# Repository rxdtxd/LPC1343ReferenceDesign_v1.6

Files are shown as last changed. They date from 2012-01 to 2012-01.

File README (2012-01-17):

This is a version of microBuilder.eu LPC1343 Reference Board [1],
slightly modified:

- the ocillator footprint is replaced with a HC49/S, these crystals
  are available locally and cheaper;
- spacings are slightly increased (manufacturer requirements);
- silkscreen is now retarded.

[1]: http://www.microbuilder.eu/Projects/LPC1343ReferenceDesign.aspx

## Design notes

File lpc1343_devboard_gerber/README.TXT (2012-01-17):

Bottom Copper     (GBL)
Bottom Silkscreen (GBO)
Bottom Soldermask (GBS)
Top Copper        (GTL)
Top Silkscreen    (GTO)
Top Soldermask 	  (GTS)
Top Paste      	  (GTP)
Drill File 	  (TXT)

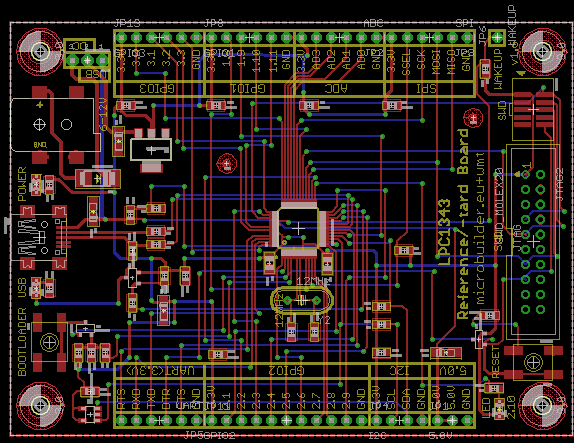
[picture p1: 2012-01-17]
Board.png

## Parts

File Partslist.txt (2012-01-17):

Partlist

Exported from LPC1343_BaseBoard_V1.6.brd at 1/17/12 9:31 PM

EAGLE Version 6.0.0 Copyright (c) 1988-2011 CadSoft

Assembly variant: 

Part     Value          Package         Library      Position (inch)       Orientation

BTN1     RESET          EVQ-Q2          microbuilder (3.48015748 0.48625984) R180
BTN2     ISP            EVQ-Q2          microbuilder (0.26015748 0.62)     R270
C1       16pF           0603            microbuilder (1.87094488 0.68984252) R90
C2       10µF           EIA3216-18/A-R  microbuilder (0.72015748 1.9615748) R90
C3       10µF           EIA3216-18/A-R  microbuilder (1.02015748 0.8315748) R90
C4       10µF           EIA3216-18/A-R  microbuilder (0.55015748 1.4915748) R270
C5       0.1µF          0603            microbuilder (3.19015748 0.80062992) R180
C6       0.1µF          0603            microbuilder (1.99015748 2.2015748) R0
C7       10µF           0805            microbuilder (2.11015748 1.1415748) R270
C8       10µF           0805            microbuilder (1.72389764 1.1484252) R270
C9       0.1µF          0603            microbuilder (2.54015748 2.2015748) R0
C10      0.1µF          0603            microbuilder (2.47015748 0.55)     R0
C11      0.1µF          0603            microbuilder (0.54047244 0.55094488) R270
C12      0.1µF          0603            microbuilder (1.16267717 1.06440945) R270
C13      10µF           EIA3216-18/A-R  microbuilder (2.90015748 0.55)     R180
C14      16pF           0603            microbuilder (2.02515748 0.69094488) R90
C15      0.1µF          0603            microbuilder (1.37015748 2.2015748) R0
C16      0.1µF          0603            microbuilder (1.38015748 0.54)     R0
C17      0.1µF          0603            microbuilder (0.77015748 2.2015748) R0
C18      0.1µF          0603            microbuilder (0.53015748 0.29)     R0
CN1      USBMINIB       USB-MINIB       microbuilder (0.19015748 1.32125984) R270
CN2      DC_2.0MM       DCJACK_2MM_SMT  microbuilder (0.19515748 2.0715748) R0
D1       BAT54C         SOT23-R         microbuilder (0.50015748 0.71094488) R0
D2       CDBA120-G      SMADIODE        microbuilder (0.58015748 1.7115748) R180
JP1      5.0V           1X03_ROUND      microbuilder (2.94015748 0.1)      R0
JP2      ADC            1X06_ROUND      microbuilder (2.19015748 2.65)     R180
JP3      SPI            1X06_ROUND      microbuilder (2.79015748 2.65)     R180
JP4      I2C            1X04_ROUND      microbuilder (2.59015748 0.1)      R0
JP5      UART           1X06_ROUND      microbuilder (0.99015748 0.1)      R180
JP6      WAKEUP         1X01_ROUND      microbuilder (3.24015748 2.6515748) R90
JP7      FIDUCIAL1X2.5  FIDUCIAL-1X2.5  microbuilder (3.08 2.11629921)     R0
JP8      GPIO1          1X06_ROUND      microbuilder (1.59015748 2.65)     R0
JP9      FIDUCIAL1X2.5  FIDUCIAL-1X2.5  microbuilder (1.44 1.81259843)     R0
JP11     GPIO2          1X11_ROUND      microbuilder (1.84015748 0.1)      R0
JP12     POWERSOURCE    JUMPER3         microbuilder (0.51149606 2.50275591) R180
JP13     GPIO3          1X06_ROUND      microbuilder (0.99015748 2.65)     R0
JTAG1                   2X05_1.27MM_SMT microbuilder (3.48015748 2.1715748) R270
JTAG2    SWD_MOLEX20    JTAG-ARM        microbuilder (3.48015748 1.2915748) R270
LED1     POWER          CHIPLED_0805    microbuilder (0.17015748 1.67125984) R0
LED2     2mA            CHIPLED_0805    microbuilder (3.25515748 0.17562992) R0
LED3     USB            CHIPLED_0805    microbuilder (0.17015748 0.98125984) R0
Q1       MMBT2907A      SOT23-R         microbuilder (0.81015748 1.0515748) R90
R1       20K            0603            microbuilder (0.45047244 0.55094488) R270
R2       10K            0603            microbuilder (2.47015748 0.86125984) R180
R3       10K            0603            microbuilder (2.47015748 0.74062992) R180
R4       10K            0603            microbuilder (2.62015748 1.2315748) R0
R5       10K            0603            microbuilder (3.16015748 2.4415748) R270
R6       1K             0603            microbuilder (0.62937008 0.55094488) R270
R7       100K           0603            microbuilder (0.97015748 1.5115748) R180
R8       1.0K           0603            microbuilder (3.22141732 0.31594488) R180
R9       150            0603            microbuilder (0.26015748 1.67125984) R270
R10      33             0603            microbuilder (0.97015748 1.2715748) R0
R11      33             0603            microbuilder (0.97015748 1.3615748) R0
R12      2K             0603            microbuilder (0.81015748 0.8815748) R270
R13      150            0603            microbuilder (0.26015748 0.98125984) R90
R14      10K            0603            microbuilder (0.80015748 1.4715748) R90
R15      10K            0603            microbuilder (1.02708661 1.06440945) R270
R19      1.5K           0603            microbuilder (0.81015748 1.2315748) R90
U1       LPC1343FBD48   LQFP48          microbuilder (1.92015748 1.37795276) R90
U2       LM1117(3.3)    SOT223-R        microbuilder (0.94015748 1.9015748) R180
U3       MCP130T        SOT23-R         microbuilder (3.11952756 0.64062992) R90
U4       24AA32AFT-I/OT SOT23-5         microbuilder (0.53015748 0.14)     R90
Y2       12MHz          HC49/S          crystal      (1.94015748 0.90094488) R180

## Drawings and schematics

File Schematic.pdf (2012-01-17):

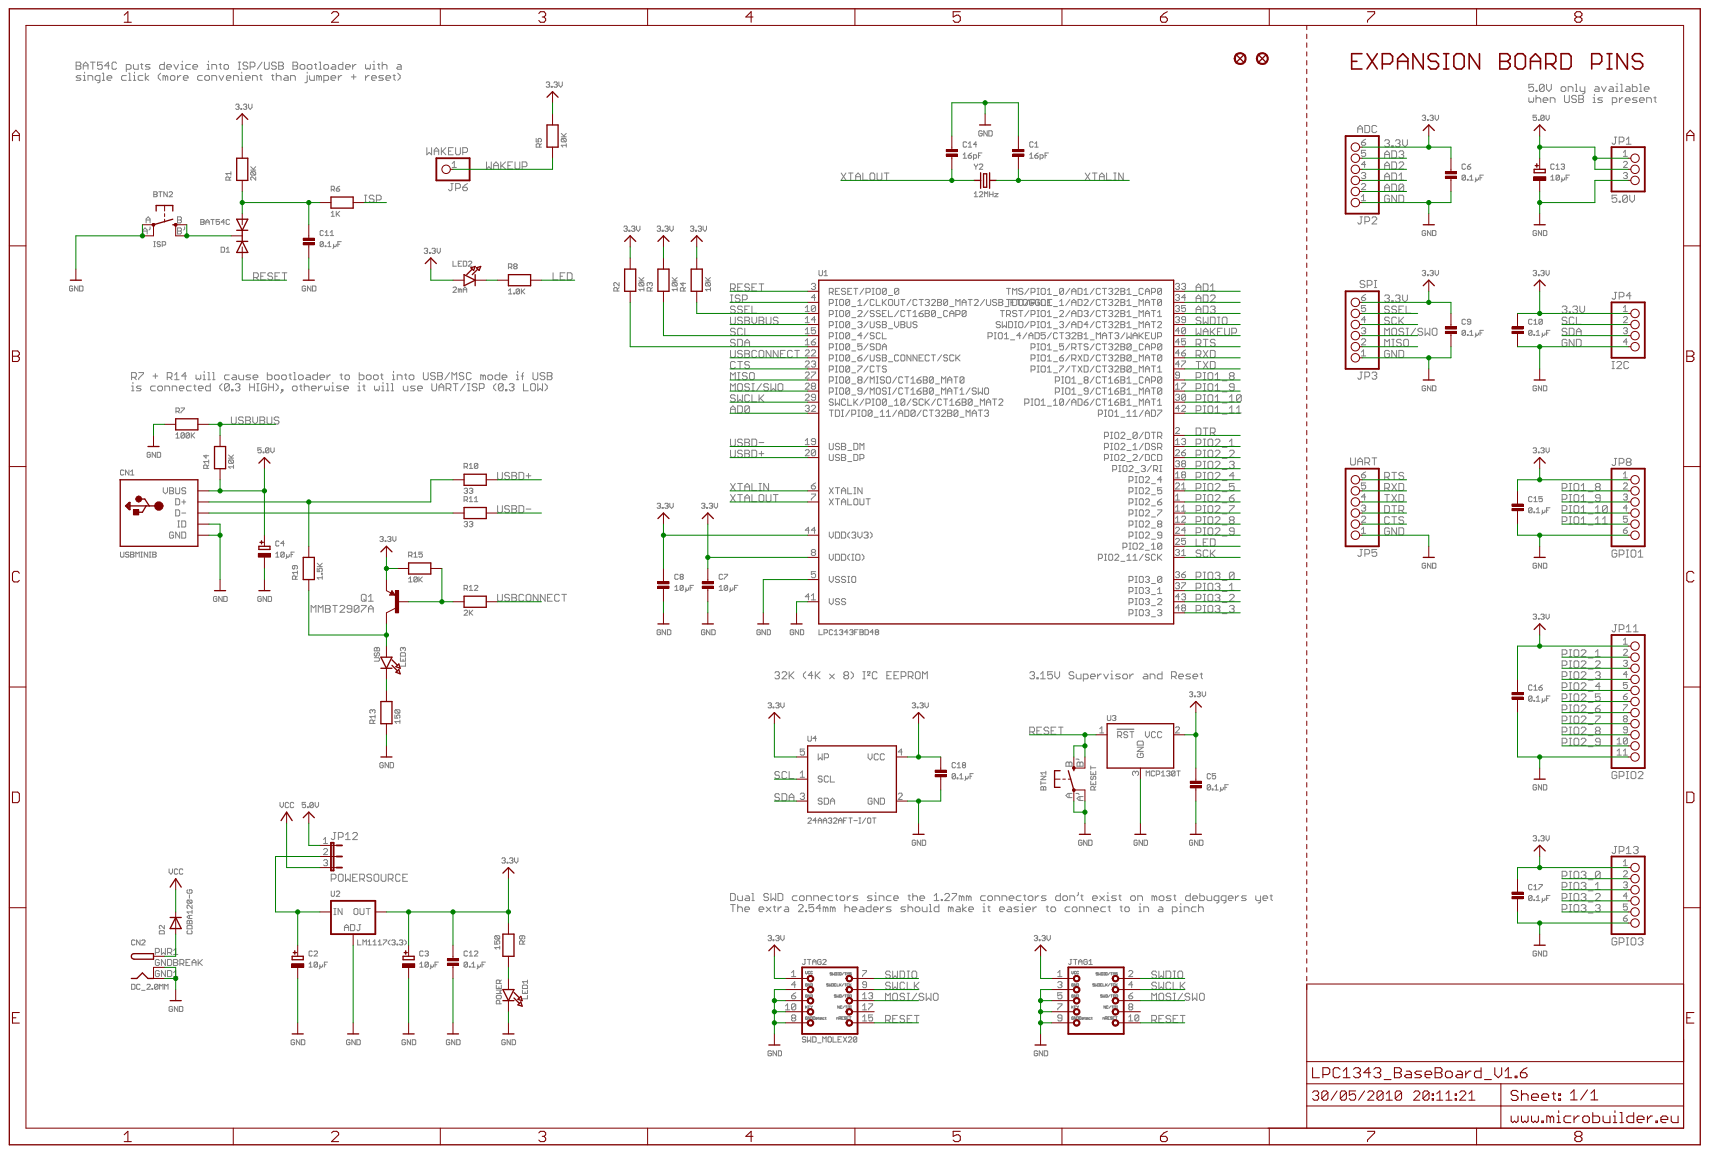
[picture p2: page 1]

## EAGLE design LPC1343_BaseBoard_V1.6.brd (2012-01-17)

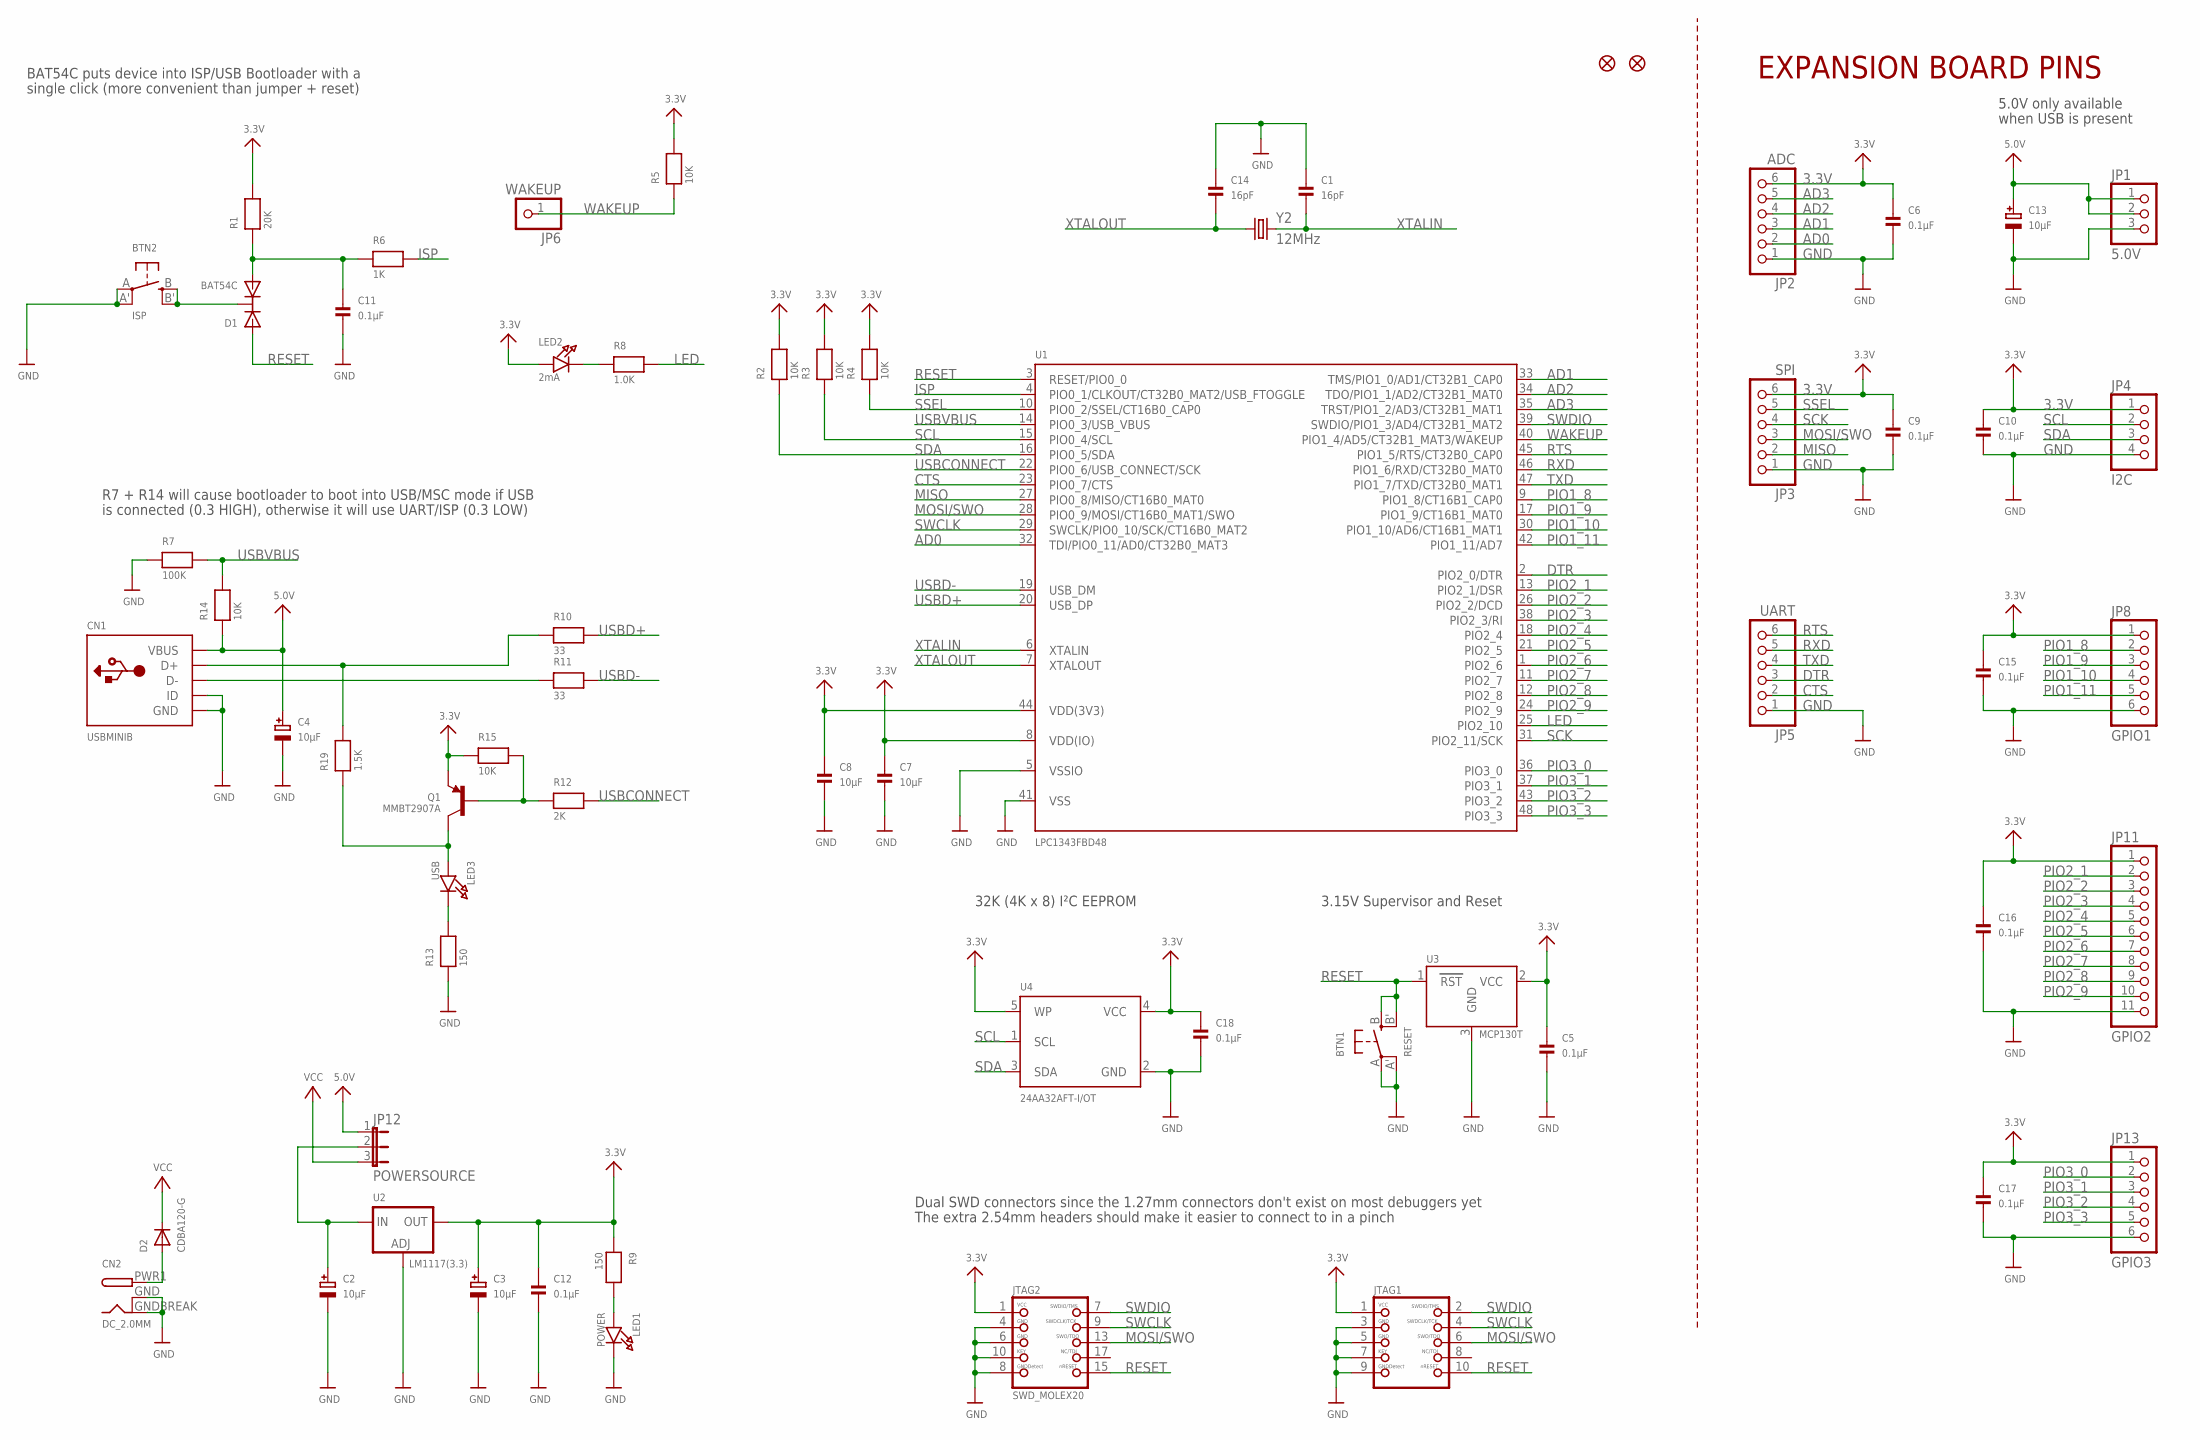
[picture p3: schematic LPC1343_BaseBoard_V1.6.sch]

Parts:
BTN1: RESET; EVQ-Q2
BTN2: ISP; EVQ-Q2
C1, C14: 16pF; 0603
C2, C3, C4, C13: 10µF; EIA3216-18/A-R
C5, C6, C9, C10, C11, C12, C15, C16, C17, C18: 0.1µF; 0603
C7, C8: 10µF; 0805
CN1: USBMINIB; USB-MINIB
CN2: DC_2.0MM; DCJACK_2MM_SMT
D1: BAT54C; SOT23-R
D2: CDBA120-G; SMADIODE
JP1: 5.0V; 1X03_ROUND
JP2: ADC; 1X06_ROUND
JP3: SPI; 1X06_ROUND
JP4: I2C; 1X04_ROUND
JP5: UART; 1X06_ROUND
JP6: WAKEUP; 1X01_ROUND
JP7, JP9: FIDUCIAL1X2.5; FIDUCIAL-1X2.5
JP8: GPIO1; 1X06_ROUND
JP11: GPIO2; 1X11_ROUND
JP12: POWERSOURCE; JUMPER3
JP13: GPIO3; 1X06_ROUND
JTAG1: JTAG-CORTEXM3; 2X05_1.27MM_SMT
JTAG2: SWD_MOLEX20; JTAG-ARM
LED1: POWER; CHIPLED_0805
LED2: 2mA; CHIPLED_0805
LED3: USB; CHIPLED_0805
Q1: MMBT2907A; SOT23-R
R1: 20K; 0603
R2, R3, R4, R5, R14, R15: 10K; 0603
R6: 1K; 0603
R7: 100K; 0603
R8: 1.0K; 0603
R9, R13: 150; 0603
R10, R11: 33; 0603
R12: 2K; 0603
R19: 1.5K; 0603
U1: LPC1343FBD48; LQFP48
U2: LM1117(3.3); SOT223-R
U3: MCP130T; SOT23-R
U4: 24AA32AFT-I/OT; SOT23-5
Y2: 12MHz; HC49/S

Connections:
3.3V: C3.+, C5.1, C6.1, C7.1, C8.1, C9.1, C10.1, C12.1, C15.1, C16.1, C17.1, C18.1, JP2.6, JP3.6, JP4.1, JP8.1, JP11.1, JP13.1, JTAG1.1, JTAG2.1, LED2.A, Q1.2 (E), R1.2, R2.2, R3.2, R4.2, R5.2, R9.1, R15.1, U1.8 (VDD(IO)), U1.44 (VDD(3V3)), U2.2 (OUT), U3.2 (VCC), U4.4 (VCC), U4.5 (WP)
5.0V: C4.+, C13.+, CN1.VBUS, JP1.1, JP1.2, JP12.1, R14.1
AD0: JP2.2, U1.32 (TDI/PIO0_11/AD0/CT32B0_MAT3)
AD1: JP2.3, U1.33 (TMS/PIO1_0/AD1/CT32B1_CAP0)
AD2: JP2.4, U1.34 (TDO/PIO1_1/AD2/CT32B1_MAT0)
AD3: JP2.5, U1.35 (TRST/PIO1_2/AD3/CT32B1_MAT1)
CTS: JP5.2, U1.23 (PIO0_7/CTS)
DTR: JP5.3, U1.2 (PIO2_0/DTR)
GND: BTN1.A, BTN1.A' (P1), BTN2.A, BTN2.A' (P1), C1.1, C2.-, C3.-, C4.-, C5.2, C6.2, C7.2, C8.2, C9.2, C10.2, C11.2, C12.2, C13.-, C14.1, C15.2, C16.2, C17.2, C18.2, CN1.GND, CN1.ID, CN2.GND (GNDBREAK), CN2.GNDBREAK (GND), JP1.3, JP2.1, JP3.1, JP4.4, JP5.1, JP8.6, JP11.11, JP13.6, JTAG1.3, JTAG1.5, JTAG1.7, JTAG1.9, JTAG2.4 (3), JTAG2.6 (5), JTAG2.8 (9), JTAG2.10 (7), LED1.C, R7.1, R13.1, U1.5 (VSSIO), U1.41 (VSS), U2.1 (ADJ), U3.3 (GND), U4.2 (GND)
ISP: R6.2, U1.4 (PIO0_1/CLKOUT/CT32B0_MAT2/USB_FTOGGLE)
LED: R8.2, U1.25 (PIO2_10)
MISO: JP3.2, U1.27 (PIO0_8/MISO/CT16B0_MAT0)
MOSI/SWO: JP3.3, JTAG1.6, JTAG2.13 (6), U1.28 (PIO0_9/MOSI/CT16B0_MAT1/SWO)
unnamed: LED2.C, R8.1
unnamed: C2.+, JP12.2, U2.3 (IN)
unnamed: CN2.PWR1 (PWR), D2.A
unnamed: BTN2.B (S), BTN2.B' (S1), D1.3 (C)
unnamed: CN1.D+, R10.1, R19.2
unnamed: Q1.1 (B), R12.1, R15.2
unnamed: C11.1, D1.2 (A2), R1.1, R6.1
unnamed: LED1.A, R9.2
unnamed: LED3.C, R13.2
unnamed: CN1.D-, R11.1
unnamed: LED3.A, Q1.3 (C), R19.1
PIO1_8: JP8.2, U1.9 (PIO1_8/CT16B1_CAP0)
PIO1_9: JP8.3, U1.17 (PIO1_9/CT16B1_MAT0)
PIO1_10: JP8.4, U1.30 (PIO1_10/AD6/CT16B1_MAT1)
PIO1_11: JP8.5, U1.42 (PIO1_11/AD7)
PIO2_1: JP11.2, U1.13 (PIO2_1/DSR)
PIO2_2: JP11.3, U1.26 (PIO2_2/DCD)
PIO2_3: JP11.4, U1.38 (PIO2_3/RI)
PIO2_4: JP11.5, U1.18 (PIO2_4)
PIO2_5: JP11.6, U1.21 (PIO2_5)
PIO2_6: JP11.7, U1.1 (PIO2_6)
PIO2_7: JP11.8, U1.11 (PIO2_7)
PIO2_8: JP11.9, U1.12 (PIO2_8)
PIO2_9: JP11.10, U1.24 (PIO2_9)
PIO3_0: JP13.2, U1.36 (PIO3_0)
PIO3_1: JP13.3, U1.37 (PIO3_1)
PIO3_2: JP13.4, U1.43 (PIO3_2)
PIO3_3: JP13.5, U1.48 (PIO3_3)
RESET: BTN1.B (S), BTN1.B' (S1), D1.1 (A1), JTAG1.10, JTAG2.15 (10), U1.3 (RESET/PIO0_0), U3.1 (RST)
RTS: JP5.6, U1.45 (PIO1_5/RTS/CT32B0_CAP0)
RXD: JP5.5, U1.46 (PIO1_6/RXD/CT32B0_MAT0)
SCK: JP3.4, U1.31 (PIO2_11/SCK)
SCL: JP4.2, R3.1, U1.15 (PIO0_4/SCL), U4.1 (SCL)
SDA: JP4.3, R2.1, U1.16 (PIO0_5/SDA), U4.3 (SDA)
SSEL: JP3.5, R4.1, U1.10 (PIO0_2/SSEL/CT16B0_CAP0)
SWCLK: JTAG1.4, JTAG2.9 (4), U1.29 (SWCLK/PIO0_10/SCK/CT16B0_MAT2)
SWDIO: JTAG1.2, JTAG2.7 (2), U1.39 (SWDIO/PIO1_3/AD4/CT32B1_MAT2)
TXD: JP5.4, U1.47 (PIO1_7/TXD/CT32B0_MAT1)
USBCONNECT: R12.2, U1.22 (PIO0_6/USB_CONNECT/SCK)
USBD+: R10.2, U1.20 (USB_DP)
USBD-: R11.2, U1.19 (USB_DM)
USBVBUS: R7.2, R14.2, U1.14 (PIO0_3/USB_VBUS)
VCC: D2.C, JP12.3
WAKEUP: JP6.1, R5.1, U1.40 (PIO1_4/AD5/CT32B1_MAT3/WAKEUP)
XTALIN: C1.2, U1.6 (XTALIN), Y2.2
XTALOUT: C14.2, U1.7 (XTALOUT), Y2.1

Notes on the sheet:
Dual SWD connectors since the 1.27mm connectors don't exist on most debuggers yet
The extra 2.54mm headers should make it easier to connect to in a pinch
3.15V Supervisor and Reset
5.0V only available
when USB is present
EXPANSION BOARD PINS
R7 + R14 will cause bootloader to boot into USB/MSC mode if USB
is connected (0.3 HIGH), otherwise it will use UART/ISP (0.3 LOW)
BAT54C puts device into ISP/USB Bootloader with a
single click (more convenient than jumper + reset)
32K (4K x 8) I²C EEPROM

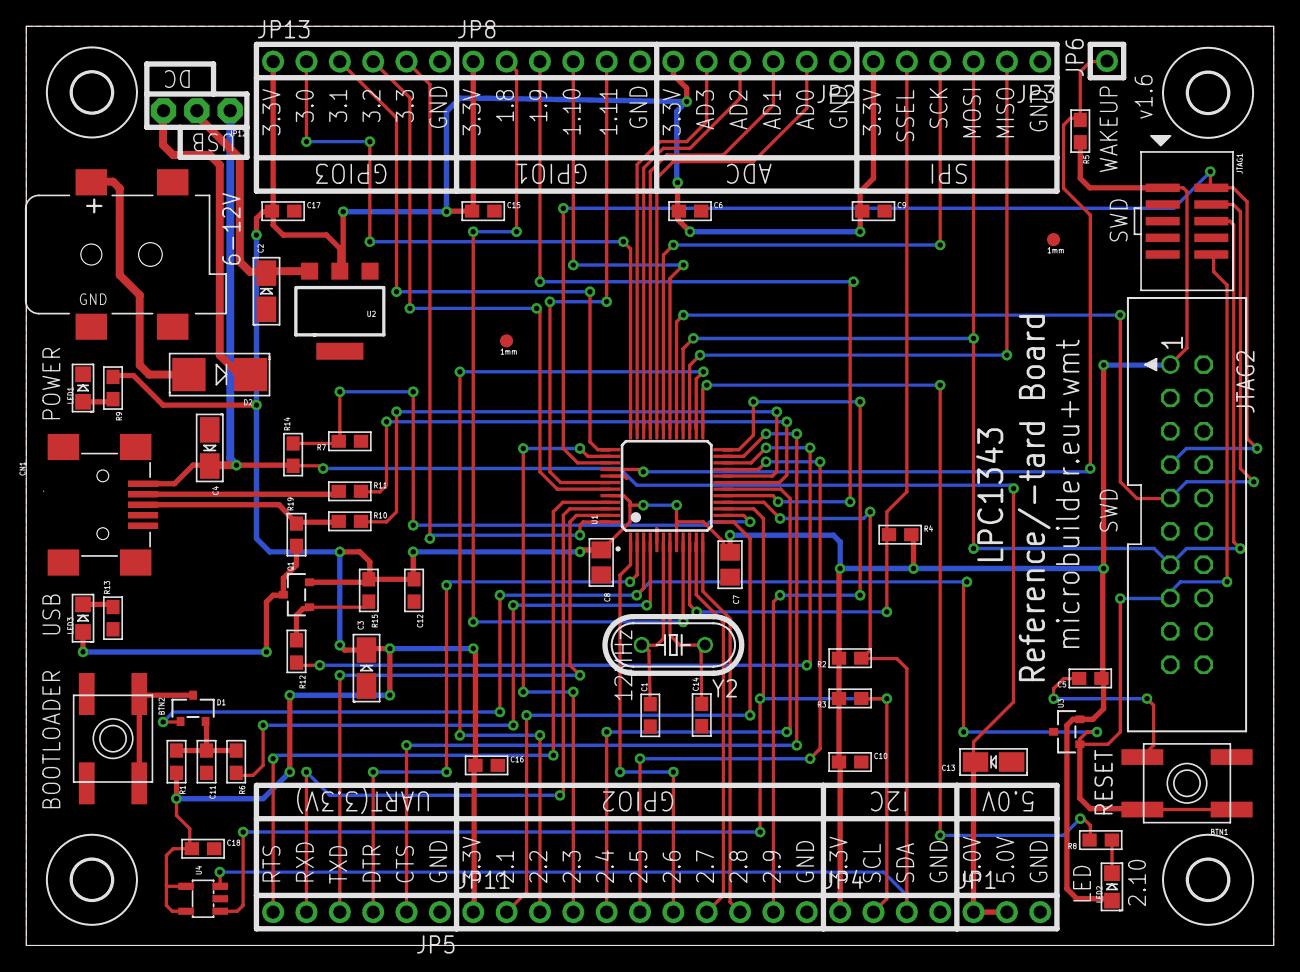
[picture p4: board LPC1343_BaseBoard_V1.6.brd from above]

Board: 2 copper layers, 95.0 x 70.0 mm, 67 parts (0 on the bottom side), 59 nets.

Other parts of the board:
U$52, U$54, U$55, U$56: MOUNTINGHOLE_3.0

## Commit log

2012-01-17 everything in one commit
    [LPC1343_BaseBoard_V1.6.brd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]
2012-01-17 oops, get back proper attribution
    [LPC1343_BaseBoard_V1.6.brd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]
